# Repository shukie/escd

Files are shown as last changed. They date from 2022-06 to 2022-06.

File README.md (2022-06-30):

# escd-diodeless keyboard

The "escd-diodeless" keyboard is a thin split keyboard with 3x6 column staggered keys, 4 thumb keys, and one big escape key (46 keys total). There are no LEDs or diodes, only for CHERRY MX Low Profile switches and Elite-C controllers.

"escd" is pronounced as "escaped.”

## Design

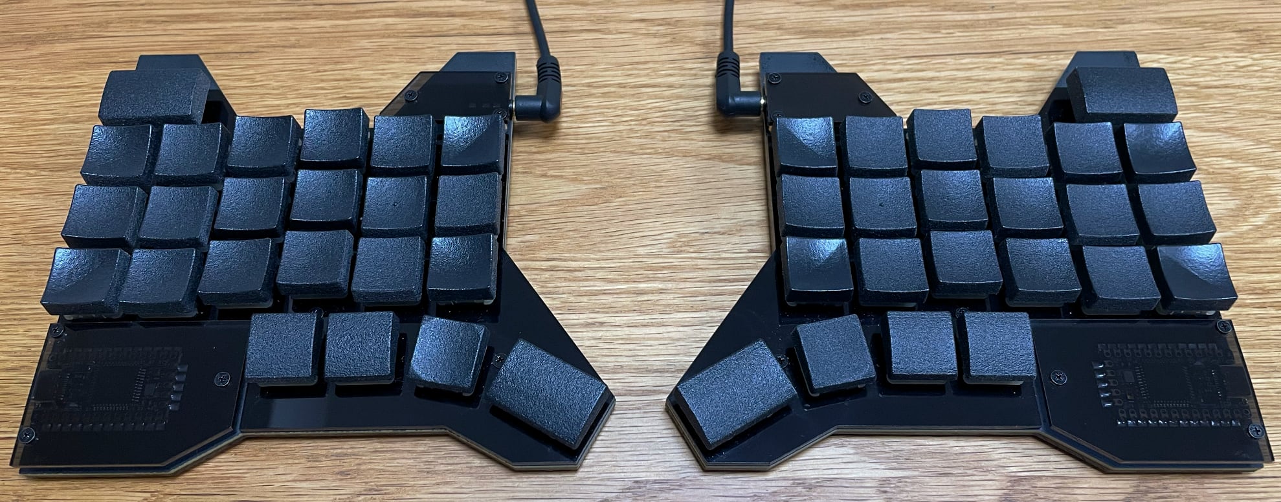
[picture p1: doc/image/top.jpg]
escd-diodeless top


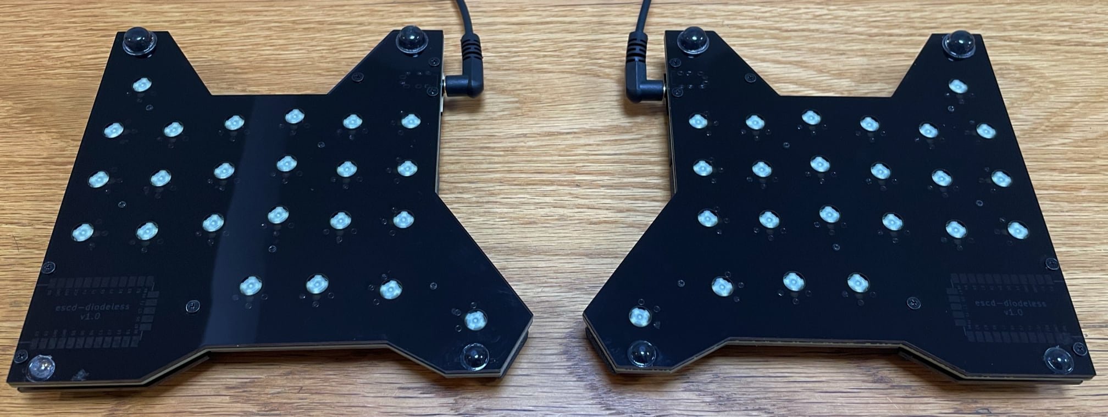
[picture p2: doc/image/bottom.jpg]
escd-diodeless bottom


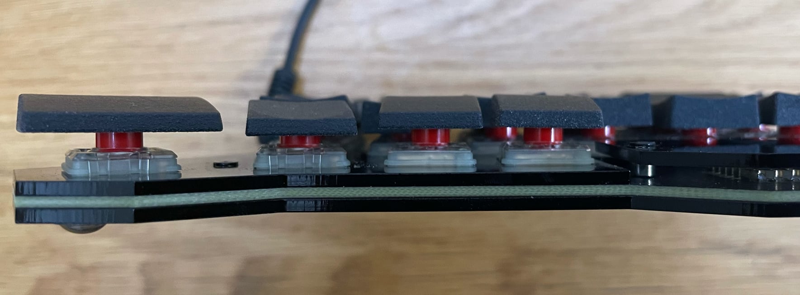
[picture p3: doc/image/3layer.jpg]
escd-diodeless 3 layer


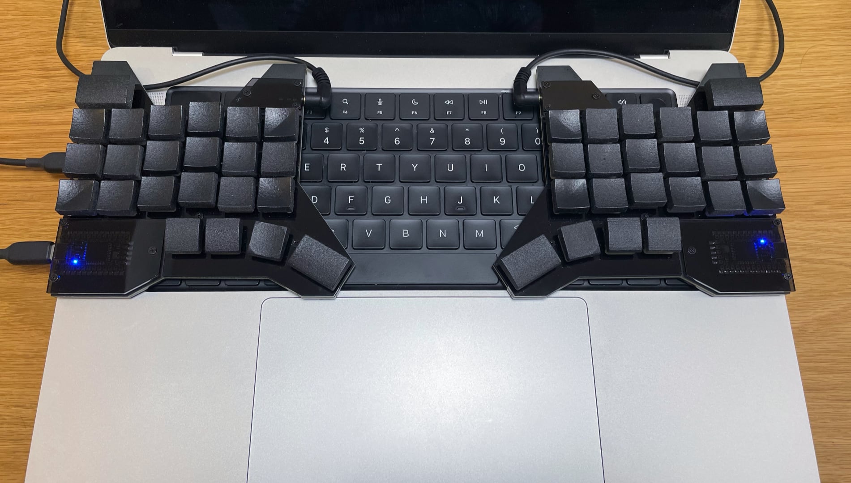
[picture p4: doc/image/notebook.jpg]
escd-diodeless on a notebook


## Directories

```text
├── doc
│   └── image
├── escd-diodeless
│   ├── firmware   ... The firmware.
│   ├── garbar     ... Garbar files For 3D printing.
│   ├── pcb        ... KiCad files for PCB.
│   └── plate      ... Inkscape files for acrylic plates.
├── keycap         ... FreeCad files for keycaps.
├── layout         ... "keyboard-layout-editor" file.
└── qmk-keyboards
    └── escd       ... The source of the firmware.
```

### Layout

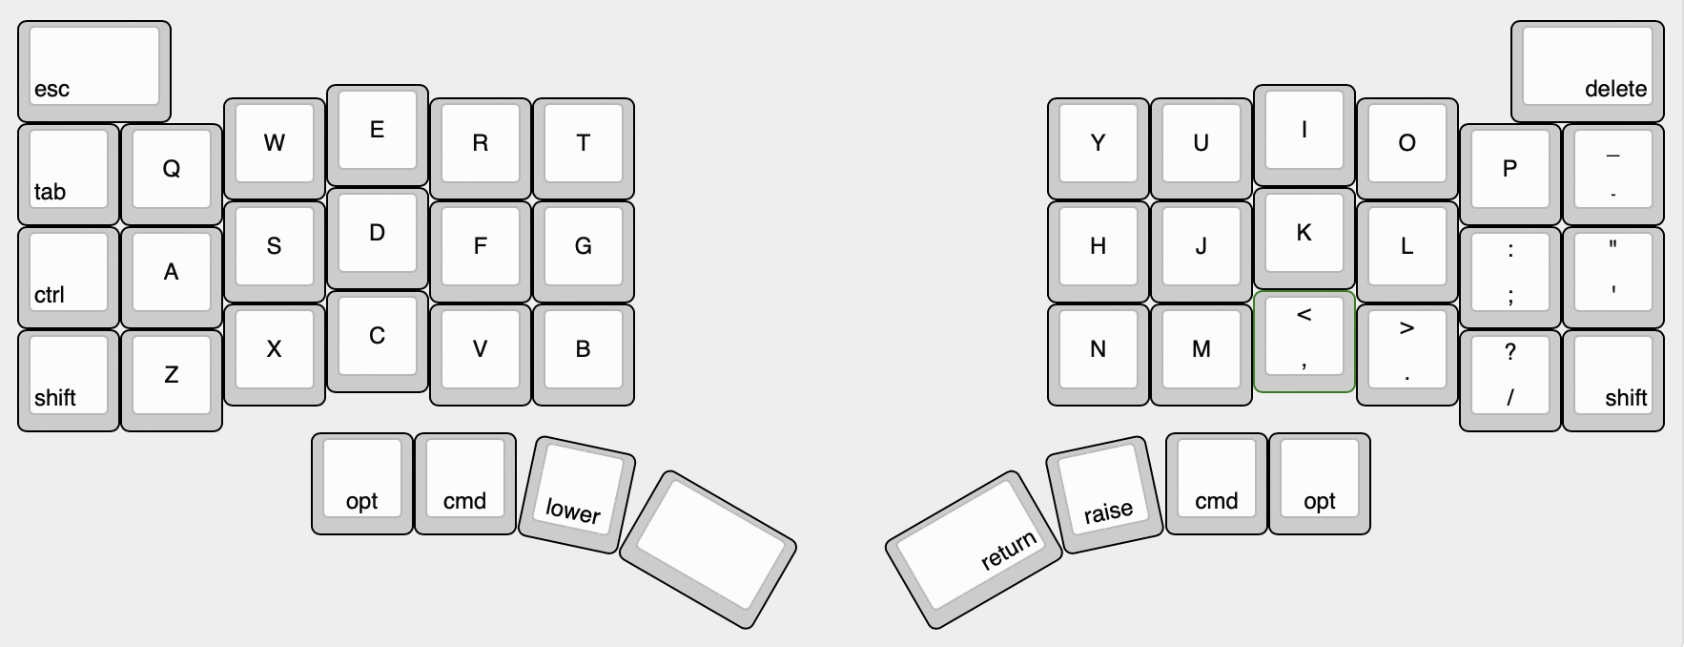
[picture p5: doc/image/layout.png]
escd-diodeless layout


### PCB

The PCB is designed reversible. The thickness is 1.6mm.

23 pins of the Elite-C controller are directly connected to switches. This is why the keyboard doesn’t need diodes.
Almost all Elite-C pins are used but a reset pin because it has a tiny reset button.

<https://deskthority.net/wiki/Elite-C#Version_4.0>

### Plates

The thickness of the acrylic plates is 2.0mm.

There are 4 types of acrylic plates. Top, bottom, and 2 little cover plates.
The bottom plates need an M2 tap work for sandwich PCB.

### Keycaps

There are 6 types of 1u (Center, CenterHome, Side, Corner, Thumb, ThumbHome) and 2 types of 1.5u (ESC, Space) keycaps designed for CHERRY MX Low Profile.

I recommend 3D printing by MJF PA11 without polishing and applying a matte clear coat on the top surface.

### Firmware

Use QMK Toolbox to install the firmware (`escd-diodeless/firmware/escd_diodeless_default.hex`) to Elite-C controllers.

`qmk-keyboards/escd` directory is for qmk_firmware. Symlink or copy the directory to the `qmk_firmware/keyboards` directory and modify [keymaps](qmk-keyboards/escd/diodeless/keymaps/default/keymap.c) if you want.

## Build guide

### Parts

- Elice-C controller x 2
- CHERRY MX Low Profile switches x 46
- TRRS jack x 2
- M2x6mm screw x 10
- M2x5mm screw x 6
- M2x3mm screw x 18
- M2x3mm spacer x 6
- M2x5mm spacer x 6
- Rubber foot x 8

- TRRS cable x 1
- Type-C USB cable x 1

### Special tool

- M2 tap

### Build steps

1. Cut the switch and TRRS jack pins so they don't protrude from the PCB.
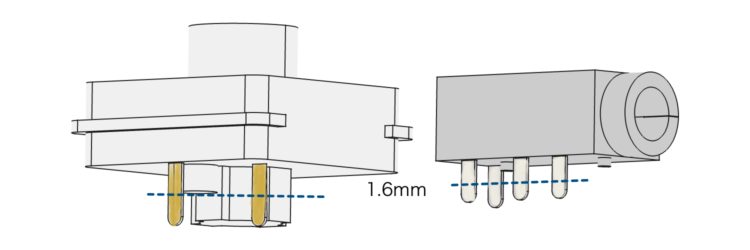
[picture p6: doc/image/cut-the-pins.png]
pins
  
2. Solder switches, TRRS jacks, and Elite-C controllers.
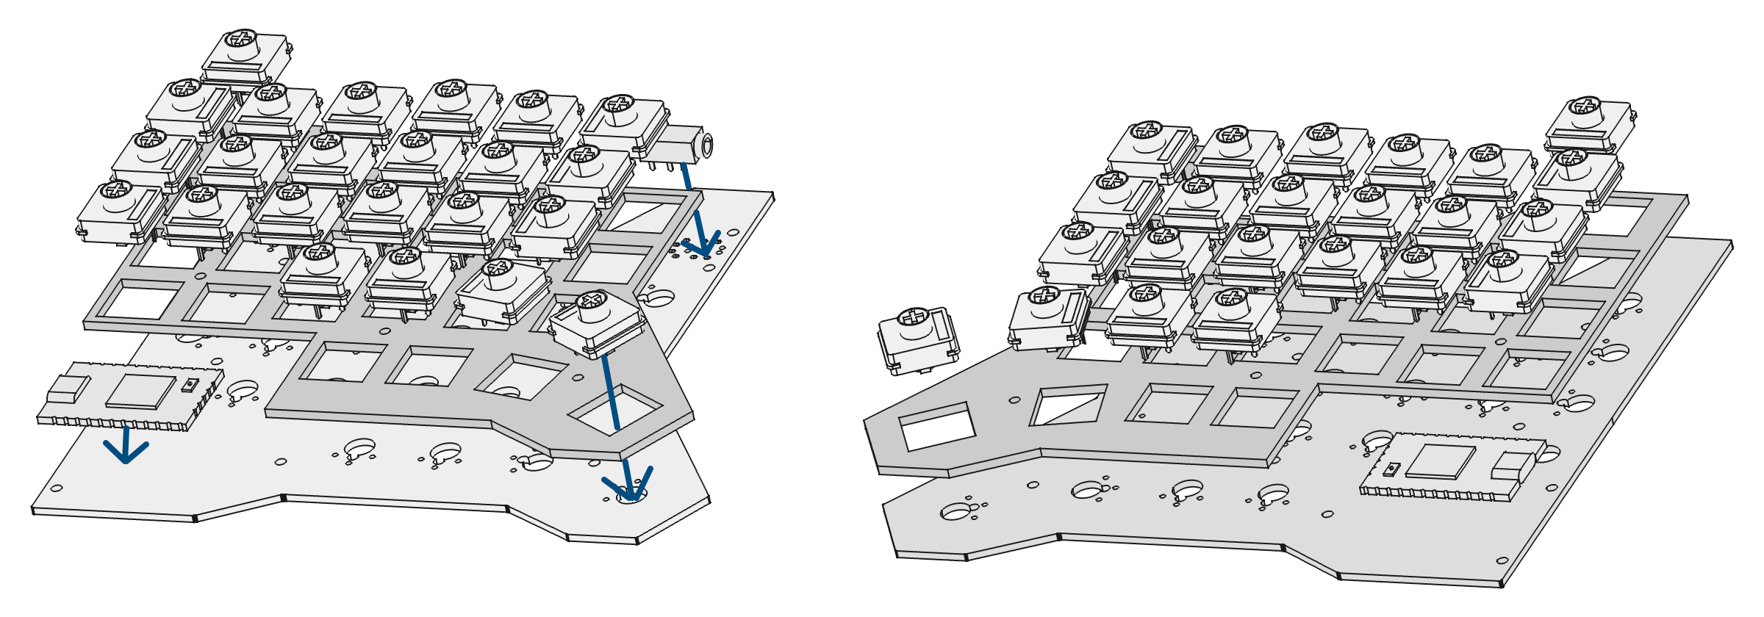
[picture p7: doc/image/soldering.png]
soldering
  
3. Install firmware and test the keyboard to make sure it works.  
  Connect the keyboard to a PC with a Type-C cable and install the firmware.  
  Connect both sides with a TRRS cable, and connect the left keyboard to the PC with the Type-C cable. Then test all keys on the keyboard.
4. Tap in the bottom plates.
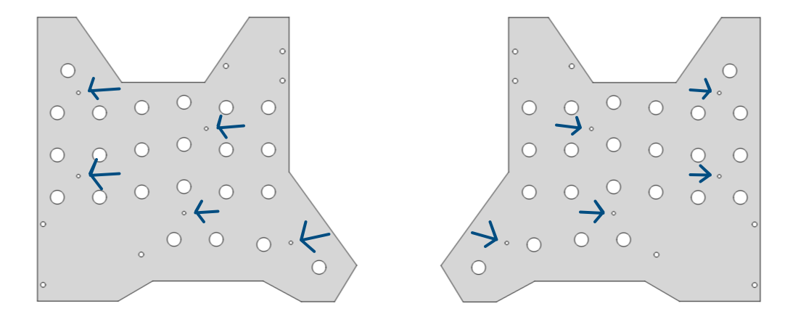
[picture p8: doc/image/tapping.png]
tapping
  
5. Put the bottom plates and covers.
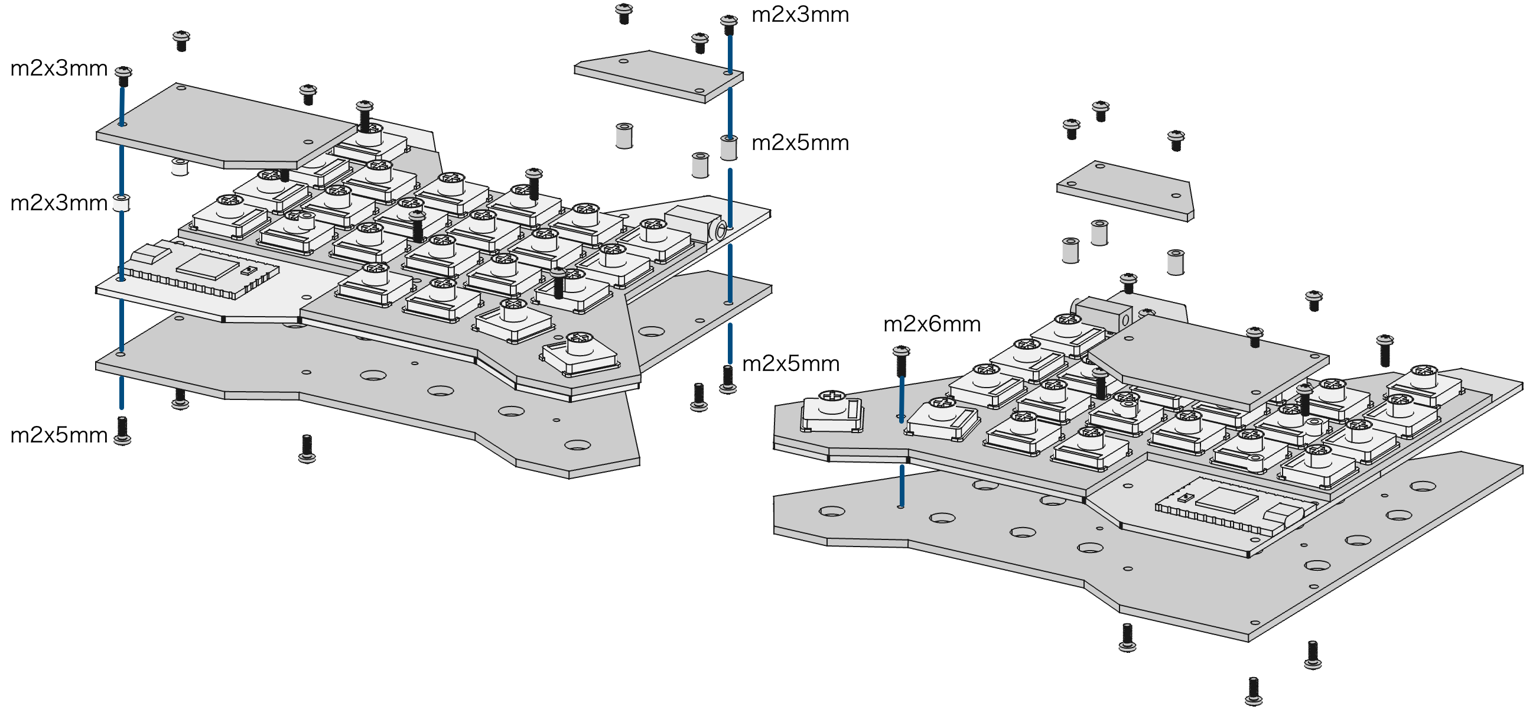
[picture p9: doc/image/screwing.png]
screwing
  
6. Put rubber feet.
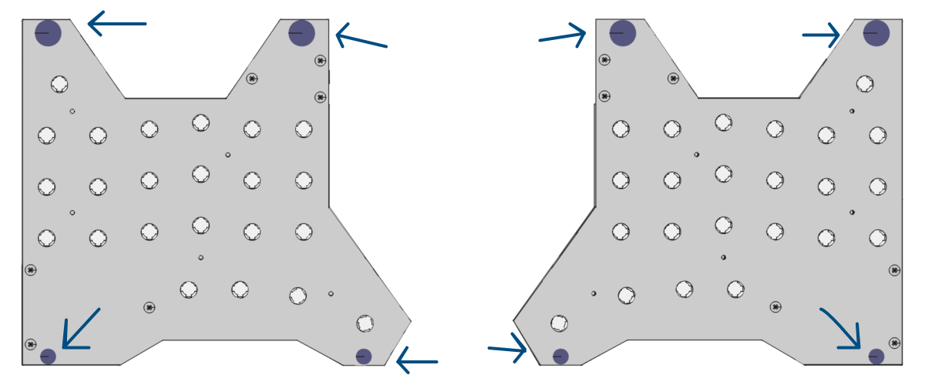
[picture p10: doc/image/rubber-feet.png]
rubber foot
  

## License

See the [LICENSE](LICENSE.txt) file for license rights and limitations (MIT).

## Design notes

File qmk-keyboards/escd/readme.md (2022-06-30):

# escd

escd

*A short description of the keyboard/project*

* Keyboard Maintainer: [shukie](https://github.com/yourusername)
* Hardware Supported: *The PCBs, controllers supported*
* Hardware Availability: *Links to where you can find this hardware*

Make example for this keyboard (after setting up your build environment):

    make escd:default

Flashing example for this keyboard ([after setting up the bootloadHID flashing environment](https://docs.qmk.fm/#/flashing_bootloadhid))

    make escd:default:flash

See the [build environment setup](https://docs.qmk.fm/#/getting_started_build_tools) and the [make instructions](https://docs.qmk.fm/#/getting_started_make_guide) for more information. Brand new to QMK? Start with our [Complete Newbs Guide](https://docs.qmk.fm/#/newbs).

## Bootloader

Enter the bootloader in 3 ways:

* **Bootmagic reset**: Hold down the key at (0,0) in the matrix (usually the top left key or Escape) and plug in the keyboard
* **BootloadHID reset**: Hold down the key connected to the `A0` and `B0` pins on the MCU if it is known (often top left or bottom left) and plug in the keyboard
* **Physical reset button**: Briefly press the button on the back of the PCB - some may have pads you must short instead
* **Keycode in layout**: Press the key mapped to `RESET` if it is available

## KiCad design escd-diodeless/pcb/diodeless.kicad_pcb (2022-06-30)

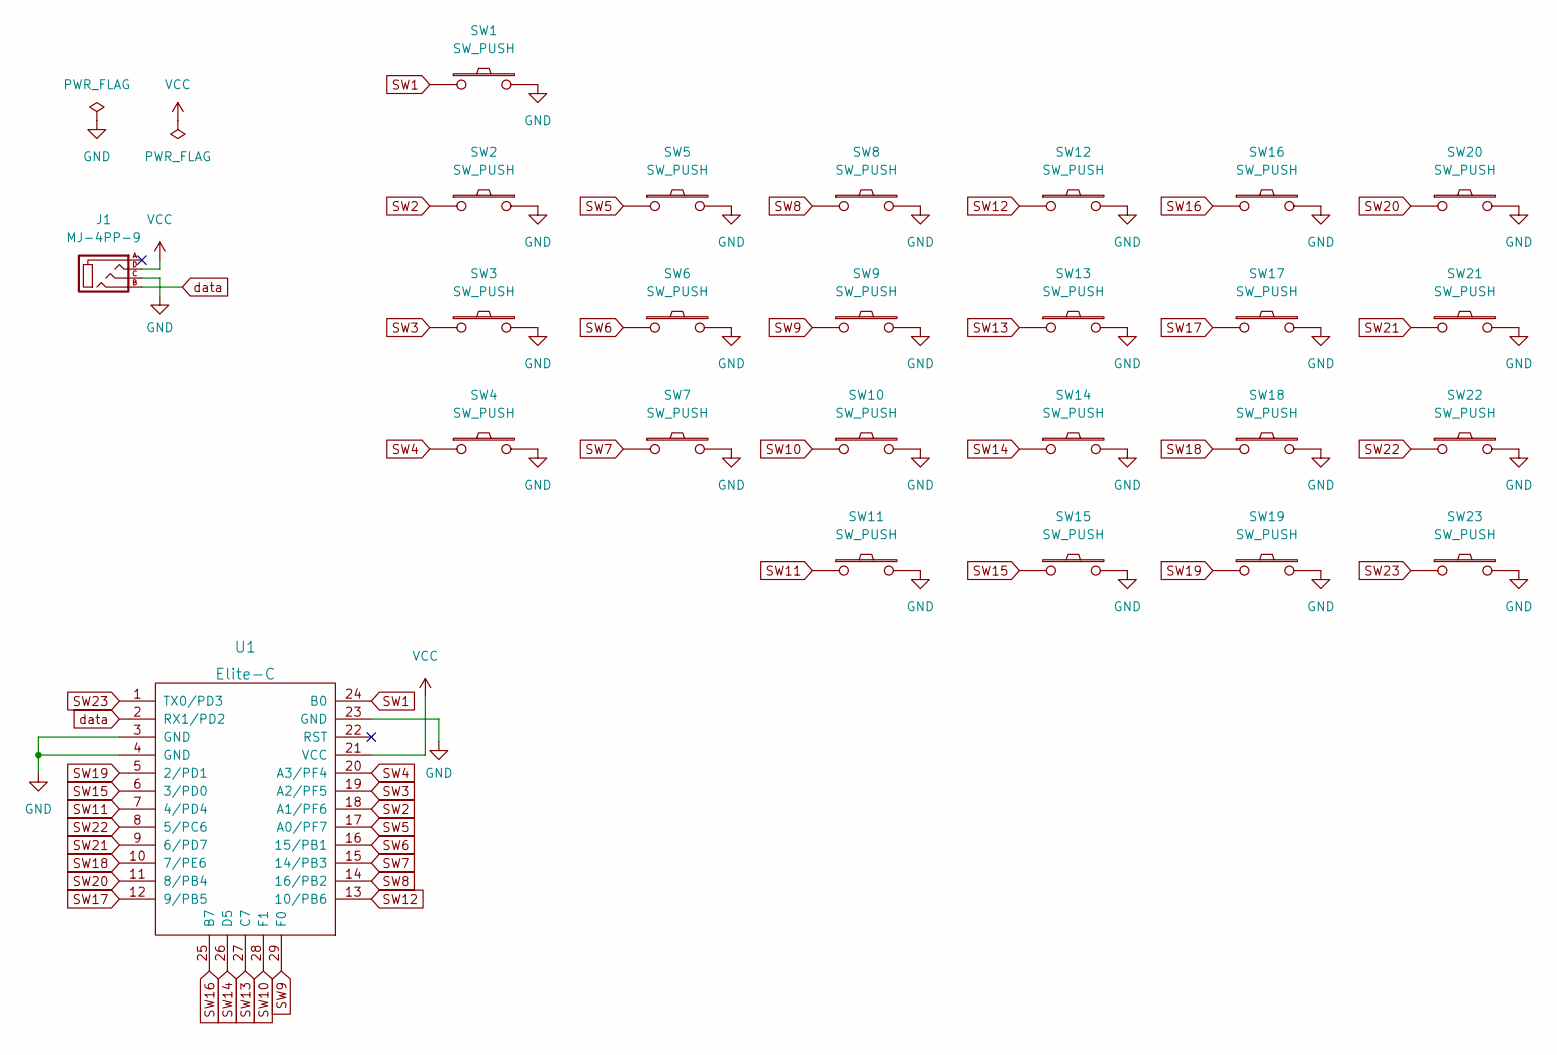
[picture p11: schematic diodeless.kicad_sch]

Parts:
J1: MJ-4PP-9
SW1: SW_PUSH; Cherry-MX-Low-Profile-u1.5
SW2, SW3, SW4, SW5, SW6, SW7, SW8, SW9, SW10, SW11, SW12, SW13, SW14, SW15, SW16, SW17, SW18, SW19, SW20, SW21, SW22: SW_PUSH; Cherry-MX-Low-Profile
SW23: SW_PUSH; Cherry-MX-Low-Profile-u1.5-vertical
U1: Elite-C; Elite-C-castellated-29pin

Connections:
GND: J1.C, SW1.2, SW2.2, SW3.2, SW4.2, SW5.2, SW6.2, SW7.2, SW8.2, SW9.2, SW10.2, SW11.2, SW12.2, SW13.2, SW14.2, SW15.2, SW16.2, SW17.2, SW18.2, SW19.2, SW20.2, SW21.2, SW22.2, SW23.2, U1.3 (GND), U1.4 (GND), U1.23 (GND)
SW1: SW1.1, U1.24 (B0)
SW2: SW2.1, U1.18 (A1/PF6)
SW3: SW3.1, U1.19 (A2/PF5)
SW4: SW4.1, U1.20 (A3/PF4)
SW5: SW5.1, U1.17 (A0/PF7)
SW6: SW6.1, U1.16 (15/PB1)
SW7: SW7.1, U1.15 (14/PB3)
SW8: SW8.1, U1.14 (16/PB2)
SW9: SW9.1, U1.29 (F0)
SW10: SW10.1, U1.28 (F1)
SW11: SW11.1, U1.7 (4/PD4)
SW12: SW12.1, U1.13 (10/PB6)
SW13: SW13.1, U1.27 (C7)
SW14: SW14.1, U1.26 (D5)
SW15: SW15.1, U1.6 (3/PD0)
SW16: SW16.1, U1.25 (B7)
SW17: SW17.1, U1.12 (9/PB5)
SW18: SW18.1, U1.10 (7/PE6)
SW19: SW19.1, U1.5 (2/PD1)
SW20: SW20.1, U1.11 (8/PB4)
SW21: SW21.1, U1.9 (6/PD7)
SW22: SW22.1, U1.8 (5/PC6)
SW23: SW23.1, U1.1 (TX0/PD3)
VCC: J1.D, U1.21 (VCC)
data: J1.B, U1.2 (RX1/PD2)

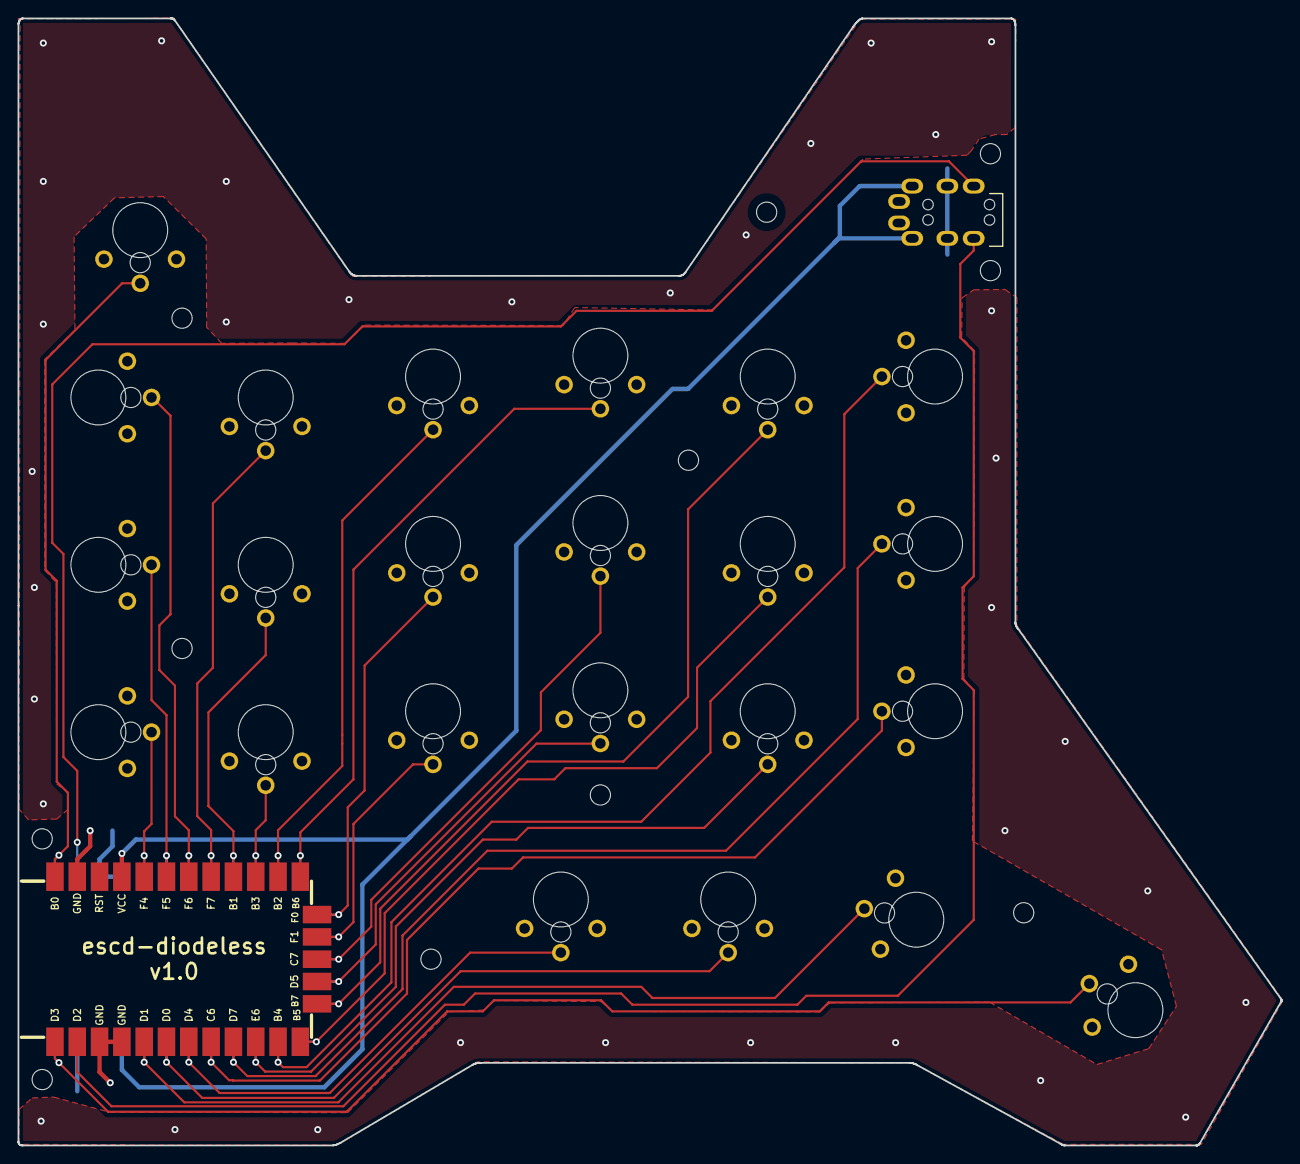
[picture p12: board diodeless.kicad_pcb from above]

Board: 2 copper layers, 143.8 x 128.3 mm, 36 parts (0 on the bottom side), 26 nets.

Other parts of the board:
H1, H2, H3, H4, H5, H6, H7, H8, H9, H10, H11: Val**; M2_HOLE_WITH_CLEARANCE

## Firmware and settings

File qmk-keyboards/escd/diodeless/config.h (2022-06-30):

// Copyright 2021 shukie (@shukie)
// SPDX-License-Identifier: GPL-2.0-or-later

#pragma once

#include "config_common.h"

/* USB Device descriptor parameter */
#define VENDOR_ID    0xA921
#define PRODUCT_ID   0x0002
#define DEVICE_VER   0x0001
#define MANUFACTURER shukie
#define PRODUCT      escd diodeless
#define DESCRIPTION  escd diodeless keyboard

/* key matrix size */
#define MATRIX_ROWS 10
#define MATRIX_COLS 6

/*
 * Keyboard Matrix Assignments
 *
 * Change this to how you wired your keyboard
 * COLS: AVR pins used for columns, left to right
 * ROWS: AVR pins used for rows, top to bottom
 * DIODE_DIRECTION: COL2ROW = COL = Anode (+), ROW = Cathode (-, marked on diode)
 *                  ROW2COL = ROW = Anode (+), COL = Cathode (-, marked on diode)
 *
 */
#define DIRECT_PINS { \
    {     B0, NO_PIN, NO_PIN, NO_PIN, NO_PIN, NO_PIN }, \
    {     F6,     F7,     B2,     B6,     B7,     B4 }, \
    {     F5,     B1,     F0,     C7,     B5,     D7 }, \
    {     F4,     B3,     F1,     D5,     E6,     C6 }, \
    { NO_PIN, NO_PIN,     D4,     D0,     D1,     D3 } \
}

#define DIRECT_PINS_RIGHT { \
    {     D3, NO_PIN, NO_PIN, NO_PIN, NO_PIN, NO_PIN }, \
    {     D4,     C6,     B4,     B5,     F0,     B2 }, \
    {     D0,     D7,     B7,     C7,     B6,     B1 }, \
    {     D1,     E6,     D5,     F1,     B3,     F7 }, \
    { NO_PIN, NO_PIN,     F6,     F5,     F4,     B0 } \
}

    // {     D3, NO_PIN, NO_PIN, NO_PIN, NO_PIN, NO_PIN },
    // {     D4,     C6,     B4,     B5,     F0,     B2 },
    // { NO_PIN, NO_PIN,     F6,     F5,     F4,     B0 }

#define UNUSED_PINS {}

//#define LED_NUM_LOCK_PIN D0
//#define LED_CAPS_LOCK_PIN D1
//#define LED_SCROLL_LOCK_PIN D6

//#define BACKLIGHT_PIN D3
//#define BACKLIGHT_LEVELS 3
//#define BACKLIGHT_BREATHING

//#define RGBLED_NUM 58
//#define RGBLIGHT_HUE_STEP 8
//#define RGBLIGHT_SAT_STEP 8
//#define RGBLIGHT_VAL_STEP 8
//#define RGBLIGHT_LIMIT_VAL 255 /* The maximum brightness level */
//#define RGBLIGHT_SLEEP  /* If defined, the RGB lighting will be switched off when the host goes to sleep */
/*== all animations enable ==*/
//#define RGBLIGHT_ANIMATIONS
/*== or choose animations ==*/
//#define RGBLIGHT_EFFECT_BREATHING
//#define RGBLIGHT_EFFECT_RAINBOW_MOOD
//#define RGBLIGHT_EFFECT_RAINBOW_SWIRL
//#define RGBLIGHT_EFFECT_SNAKE
//#define RGBLIGHT_EFFECT_KNIGHT
//#define RGBLIGHT_EFFECT_CHRISTMAS
//#define RGBLIGHT_EFFECT_STATIC_GRADIENT
//#define RGBLIGHT_EFFECT_RGB_TEST
//#define RGBLIGHT_EFFECT_ALTERNATING
/*== customize breathing effect ==*/
/*==== (DEFAULT) use fixed table instead of exp() and sin() ====*/
//#define RGBLIGHT_BREATHE_TABLE_SIZE 256      // 256(default) or 128 or 64
/*==== use exp() and sin() ====*/
//#define RGBLIGHT_EFFECT_BREATHE_CENTER 1.85  // 1 to 2.7
//#define RGBLIGHT_EFFECT_BREATHE_MAX    255   // 0 to 255

/* Debounce reduces chatter (unintended double-presses) - set 0 if debouncing is not needed */
#define DEBOUNCE 5

/* define if matrix has ghost (lacks anti-ghosting diodes) */
//#define MATRIX_HAS_GHOST

/* Mechanical locking support. Use KC_LCAP, KC_LNUM or KC_LSCR instead in keymap */
#define LOCKING_SUPPORT_ENABLE
/* Locking resynchronize hack */
#define LOCKING_RESYNC_ENABLE

/* If defined, GRAVE_ESC will always act as ESC when CTRL is held.
 * This is useful for the Windows task manager shortcut (ctrl+shift+esc).
 */
//#define GRAVE_ESC_CTRL_OVERRIDE

/*
 * Force NKRO
 *
 * Force NKRO (nKey Rollover) to be enabled by default, regardless of the saved
 * state in the bootmagic EEPROM settings. (Note that NKRO must be enabled in the
 * makefile for this to work.)
 *
 * If forced on, NKRO can be disabled via magic key (default = LShift+RShift+N)
 * until the next keyboard reset.
 *
 * NKRO may prevent your keystrokes from being detected in the BIOS, but it is
 * fully operational during normal computer usage.
 *
 * For a less heavy-handed approach, enable NKRO via magic key (LShift+RShift+N)
 * or via bootmagic (hold SPACE+N while plugging in the keyboard). Once set by
 * bootmagic, NKRO mode will always be enabled until it is toggled again during a
 * power-up.
 *
 */
//#define FORCE_NKRO

/*
 * Feature disable options
 *  These options are also useful to firmware size reduction.
 */

/* disable debug print */
//#define NO_DEBUG

/* disable print */
//#define NO_PRINT

/* disable action features */
//#define NO_ACTION_LAYER
//#define NO_ACTION_TAPPING
//#define NO_ACTION_ONESHOT

/* disable these deprecated features by default */
#define NO_ACTION_MACRO
#define NO_ACTION_FUNCTION

/* Bootmagic Lite key configuration */
//#define BOOTMAGIC_LITE_ROW 0
//#define BOOTMAGIC_LITE_COLUMN 0


/* escd */
// https://docs.qmk.fm/#/feature_split_keyboard?id=handedness-by-define
#define MASTER_LEFT

// https://docs.qmk.fm/#/feature_split_keyboard?id=communication-options
#define SOFT_SERIAL_PIN D2
